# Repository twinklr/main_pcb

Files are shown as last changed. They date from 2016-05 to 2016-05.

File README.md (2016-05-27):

# Twinklr Main Board

This repository contains layouts for the Twinklr main PCB in EAGLE's `brd` and `sch` formats. Gerber files are also included.

## `twinklr_board`

This was the original Twinklr board with a built-in 1W amplifier. Unfortunately, it doesn't really work very well, so the amplifier was removed from the final version.

## `twinklr_board_5v`

This is the board used in the current version of Twinklr. It distributes 5V from a tip-negative PSU to the Raspberry Pi, rather than stepping down 9V with a regulator. It has no amplifier.

## License  

Twinklr is Open Hardware.

<br /><span
xmlns:dct="http://purl.org/dc/terms/" property="dct:title">Twinklr</span> by
<span xmlns:cc="http://creativecommons.org/ns#"
property="cc:attributionName">Tom Armitage and Richard Birkin</span> is Open
Hardware. It is licensed under a <a rel="license"
href="http://creativecommons.org/licenses/by-sa/4.0/">Creative Commons
Attribution-ShareAlike 4.0 International License</a>  
If you use any work in this project, you should credit us, and you must
republish any changes you make under the same license. This license does permit
commercial use of these designs, but consider getting in touch before selling
anything.

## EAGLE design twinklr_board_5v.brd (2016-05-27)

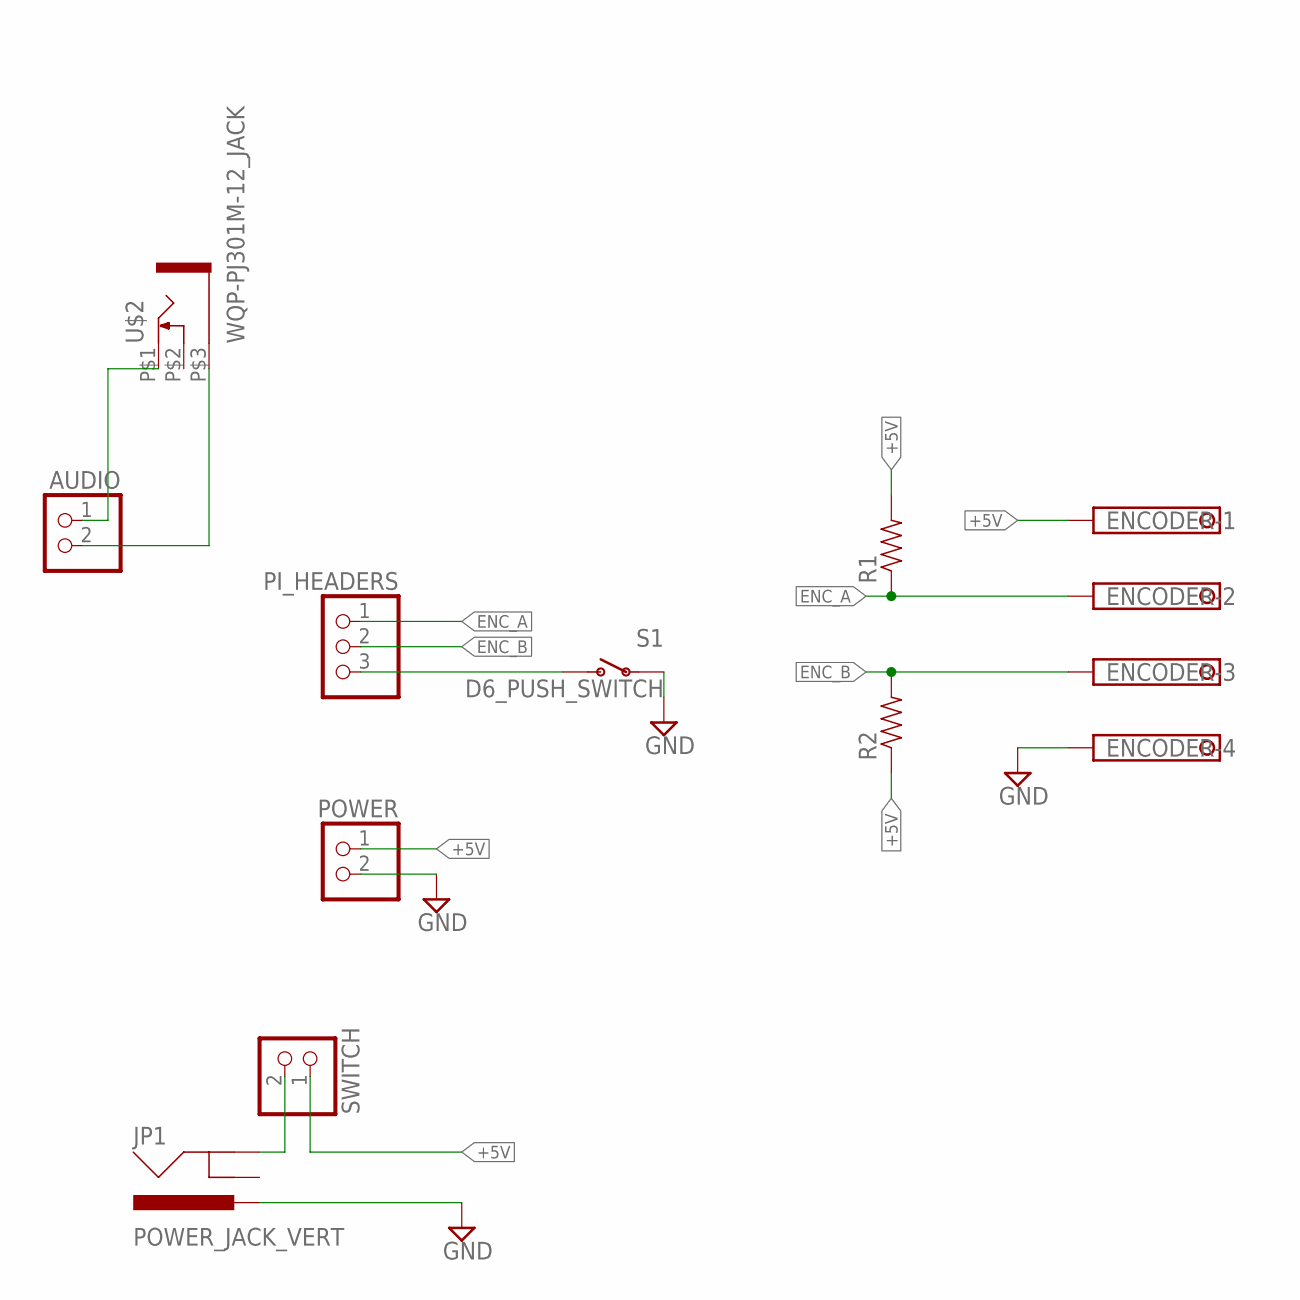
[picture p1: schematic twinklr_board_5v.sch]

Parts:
AUDIO: PINHD-1X2; 1X02
ENCODER: 1751264
JP1: POWER_JACK_VERT
PI_HEADERS: PINHD-1X3; 1X03
POWER: PINHD-1X2; 1X02
R1, R2: RESISTORAXIAL-0.3; AXIAL-0.3
S1: D6_PUSH_SWITCH
SWITCH: PINHD-1X2; 1X02
U$2: WQP-PJ301M-12_JACK

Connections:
+5V: ENCODER.1, POWER.1, R1.P$2 (2), R2.P$1 (1), SWITCH.1
ENC_A: ENCODER.2, PI_HEADERS.1, R1.P$1 (1)
ENC_B: ENCODER.3, PI_HEADERS.2, R2.P$2 (2)
GND: ENCODER.4, JP1.PWR, POWER.2, S1.P$3, S1.P$4
unnamed: AUDIO.2, U$2.P$3 (1)
unnamed: AUDIO.1, U$2.P$1 (2)
unnamed: JP1.GND, SWITCH.2
unnamed: PI_HEADERS.3, S1.P$1 (O), S1.P$2 (O)

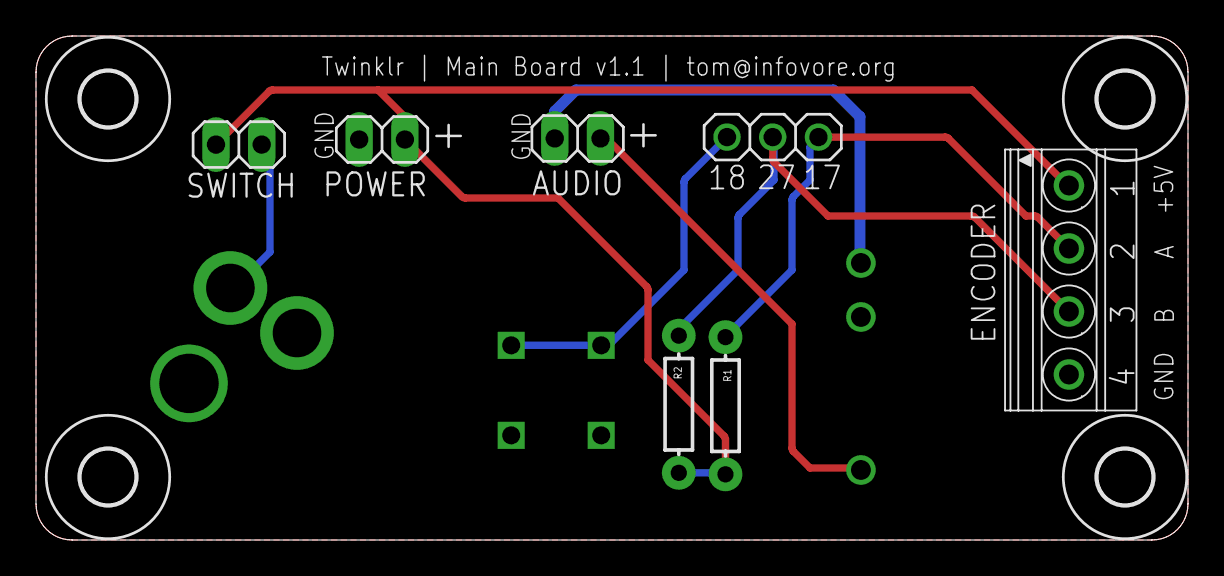
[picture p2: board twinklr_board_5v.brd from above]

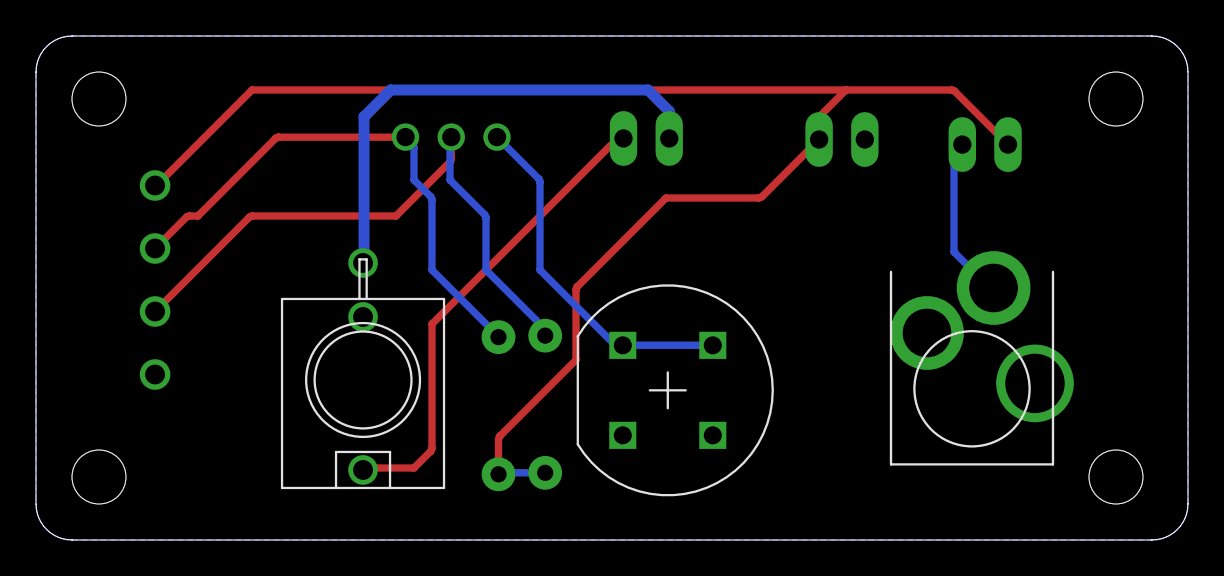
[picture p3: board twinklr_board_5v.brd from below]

Board: 2 copper layers, 64.0 x 28.0 mm, 14 parts (3 on the bottom side), 8 nets.

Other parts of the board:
U$1, U$3, U$4, U$5: 3,0

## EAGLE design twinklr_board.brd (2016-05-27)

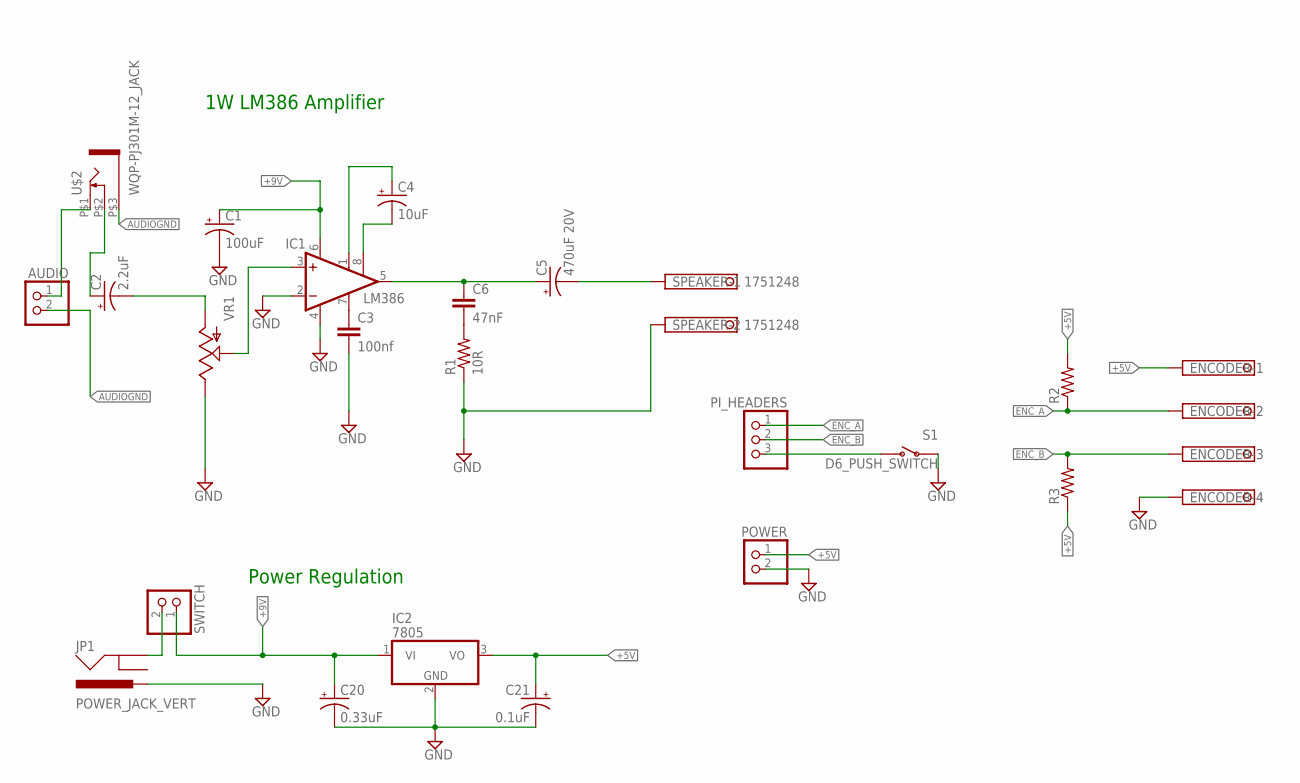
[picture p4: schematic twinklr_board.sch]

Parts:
AUDIO: PINHD-1X2; 1X02
C1: 100uF; CPOL-RADIAL-10UF-25V
C2: 2.2uF; CPOL-RADIAL-10UF-25V
C3: 100nf; CAP-PTH-SMALL
C4: 10uF; CPOL-RADIAL-10UF-25V
C5: 470uF 20V; CPOL-RADIAL-1000UF-25V
C6: 47nF; AXIAL-5MM
C20: 0.33uF; CPOL-RADIAL-10UF-25V
C21: 0.1uF; CPOL-RADIAL-10UF-25V
ENCODER: 1751264
IC1: LM386; DIL08
IC2: 7805; TO220V
JP1: POWER_JACK_VERT
PI_HEADERS: PINHD-1X3; 1X03
POWER: PINHD-1X2; 1X02
R1: 10R; AXIAL-0.3
R2, R3: RESISTORAXIAL-0.3; AXIAL-0.3
S1: D6_PUSH_SWITCH
SPEAKER: 1751248
SWITCH: PINHD-1X2; 1X02
U$2: WQP-PJ301M-12_JACK
VR1: POT; ALPS_POT

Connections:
+5V: C21.1 (+), ENCODER.1, IC2.3 (VO), POWER.1, R2.P$2 (2), R3.P$1 (1)
+9V: C1.1 (+), C20.1 (+), IC1.6 (VS), IC2.1 (VI), SWITCH.1
AUDIOGND: AUDIO.2, U$2.P$3 (1)
ENC_A: ENCODER.2, PI_HEADERS.1, R2.P$1 (1)
ENC_B: ENCODER.3, PI_HEADERS.2, R3.P$2 (2)
GND: C1.2 (-), C3.2, C20.2 (-), C21.2 (-), ENCODER.4, IC1.2 (-IN), IC1.4 (GND), IC2.2 (GND), JP1.PWR, POWER.2, R1.P$1 (1), S1.P$3, S1.P$4, SPEAKER.2, VR1.P$1 (E)
unnamed: AUDIO.1, U$2.P$1 (2)
unnamed: C2.2 (-), VR1.P$3 (A)
unnamed: IC1.3 (+IN), VR1.P$2 (S)
unnamed: C4.1 (+), IC1.1 (GAIN)
unnamed: C4.2 (-), IC1.8 (GAIN)
unnamed: C5.+, C6.P$1 (1), IC1.5 (OUT)
unnamed: C2.1 (+), U$2.P$2 (3)
unnamed: C6.P$2 (2), R1.P$2 (2)
unnamed: C5.-, SPEAKER.1
unnamed: C3.1, IC1.7 (BYPASS)
unnamed: JP1.GND, SWITCH.2
unnamed: PI_HEADERS.3, S1.P$1 (O), S1.P$2 (O)

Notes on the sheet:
1W LM386 Amplifier
Power Regulation

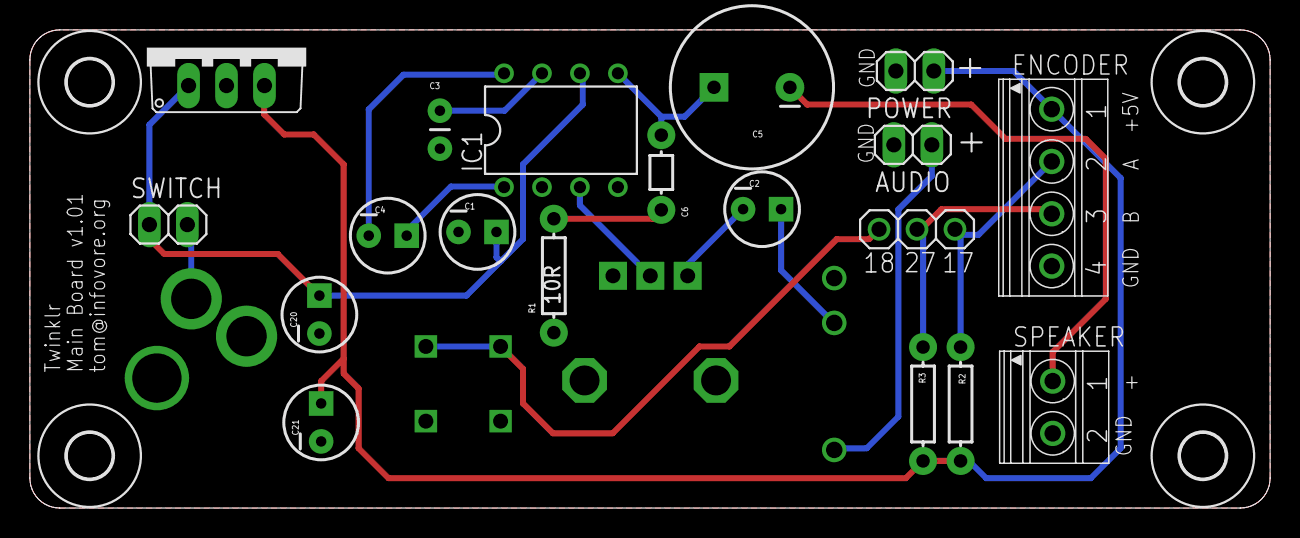
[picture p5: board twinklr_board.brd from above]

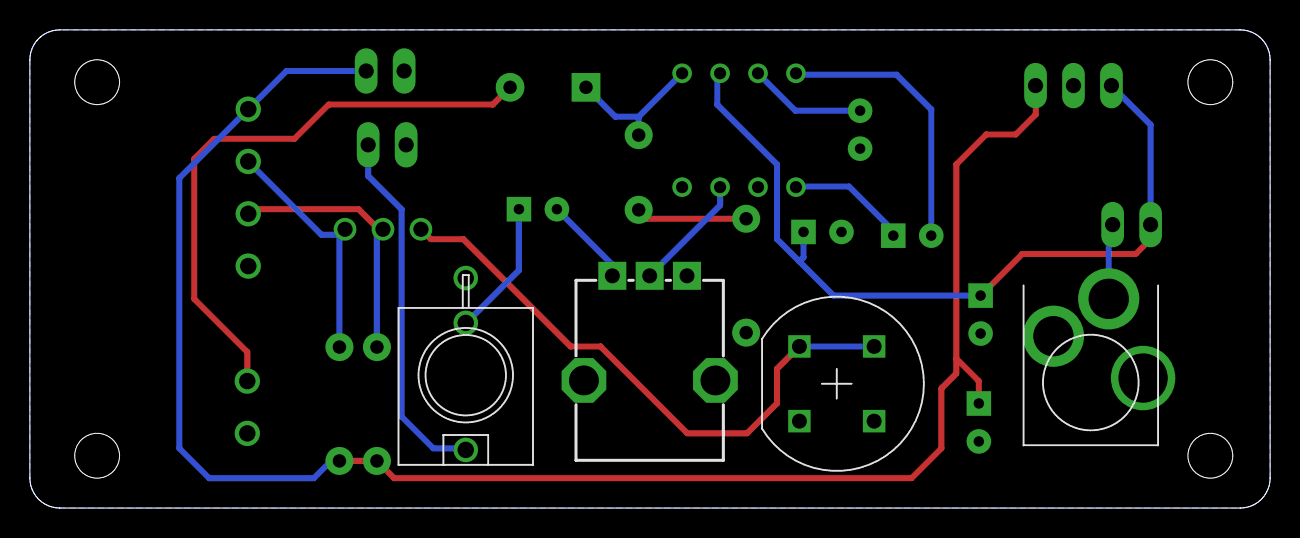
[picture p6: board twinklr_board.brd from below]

Board: 2 copper layers, 83.0 x 32.0 mm, 27 parts (4 on the bottom side), 18 nets.

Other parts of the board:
U$1, U$3, U$4, U$5: 3,0

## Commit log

2016-04-25 First commit: work on a rear PCB for Twinklr.
    [twinklr_board.brd, twinklr_board.sch]
2016-05-10 Making a production board for Ragworm.
    [twinklr_board.brd, twinklr_board.sch]
2016-05-20 Gerbers for main board.
    [twinklr_board.drills.xln]
2016-05-27 Yanking out audio ground.
    [twinklr_board.brd, twinklr_board.sch]
2016-05-27 5V board.
    [twinklr_board_5v.brd, twinklr_board_5v.sch]
2016-05-27 Missed this out.
    [twinklr_board_5v.brd]

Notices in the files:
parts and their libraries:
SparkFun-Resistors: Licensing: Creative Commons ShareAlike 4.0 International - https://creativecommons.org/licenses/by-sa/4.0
